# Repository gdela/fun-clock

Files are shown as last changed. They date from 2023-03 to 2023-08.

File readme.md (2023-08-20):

Alarm Clock with Oversleep Prevention
=====================================

Features:

- automatic time synchronization with NTP server over WiFi
- old-style TIL311 hexadecimal display
- two alarm settings: for weekdays and for weekends
- alarm starts gently with some nature sounds for a couple of minutes
- alarm ends with very loud energetic music to make sure you hear it
- to turn alarm off you need to read three random numbers and enter them back
- this makes sure that you are fully awake and do not oversleep the alarm

There is no documentation for this project, as this is rather for my own purposes.
Feel free to reverse-engineer it.

<p align="center">
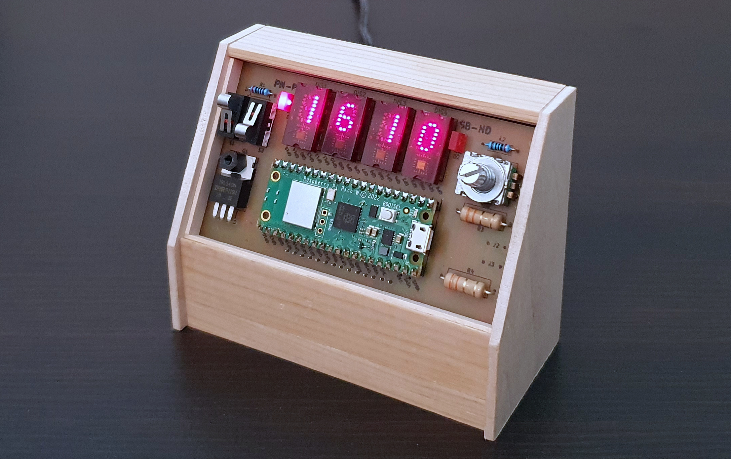
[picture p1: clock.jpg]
    
</p>

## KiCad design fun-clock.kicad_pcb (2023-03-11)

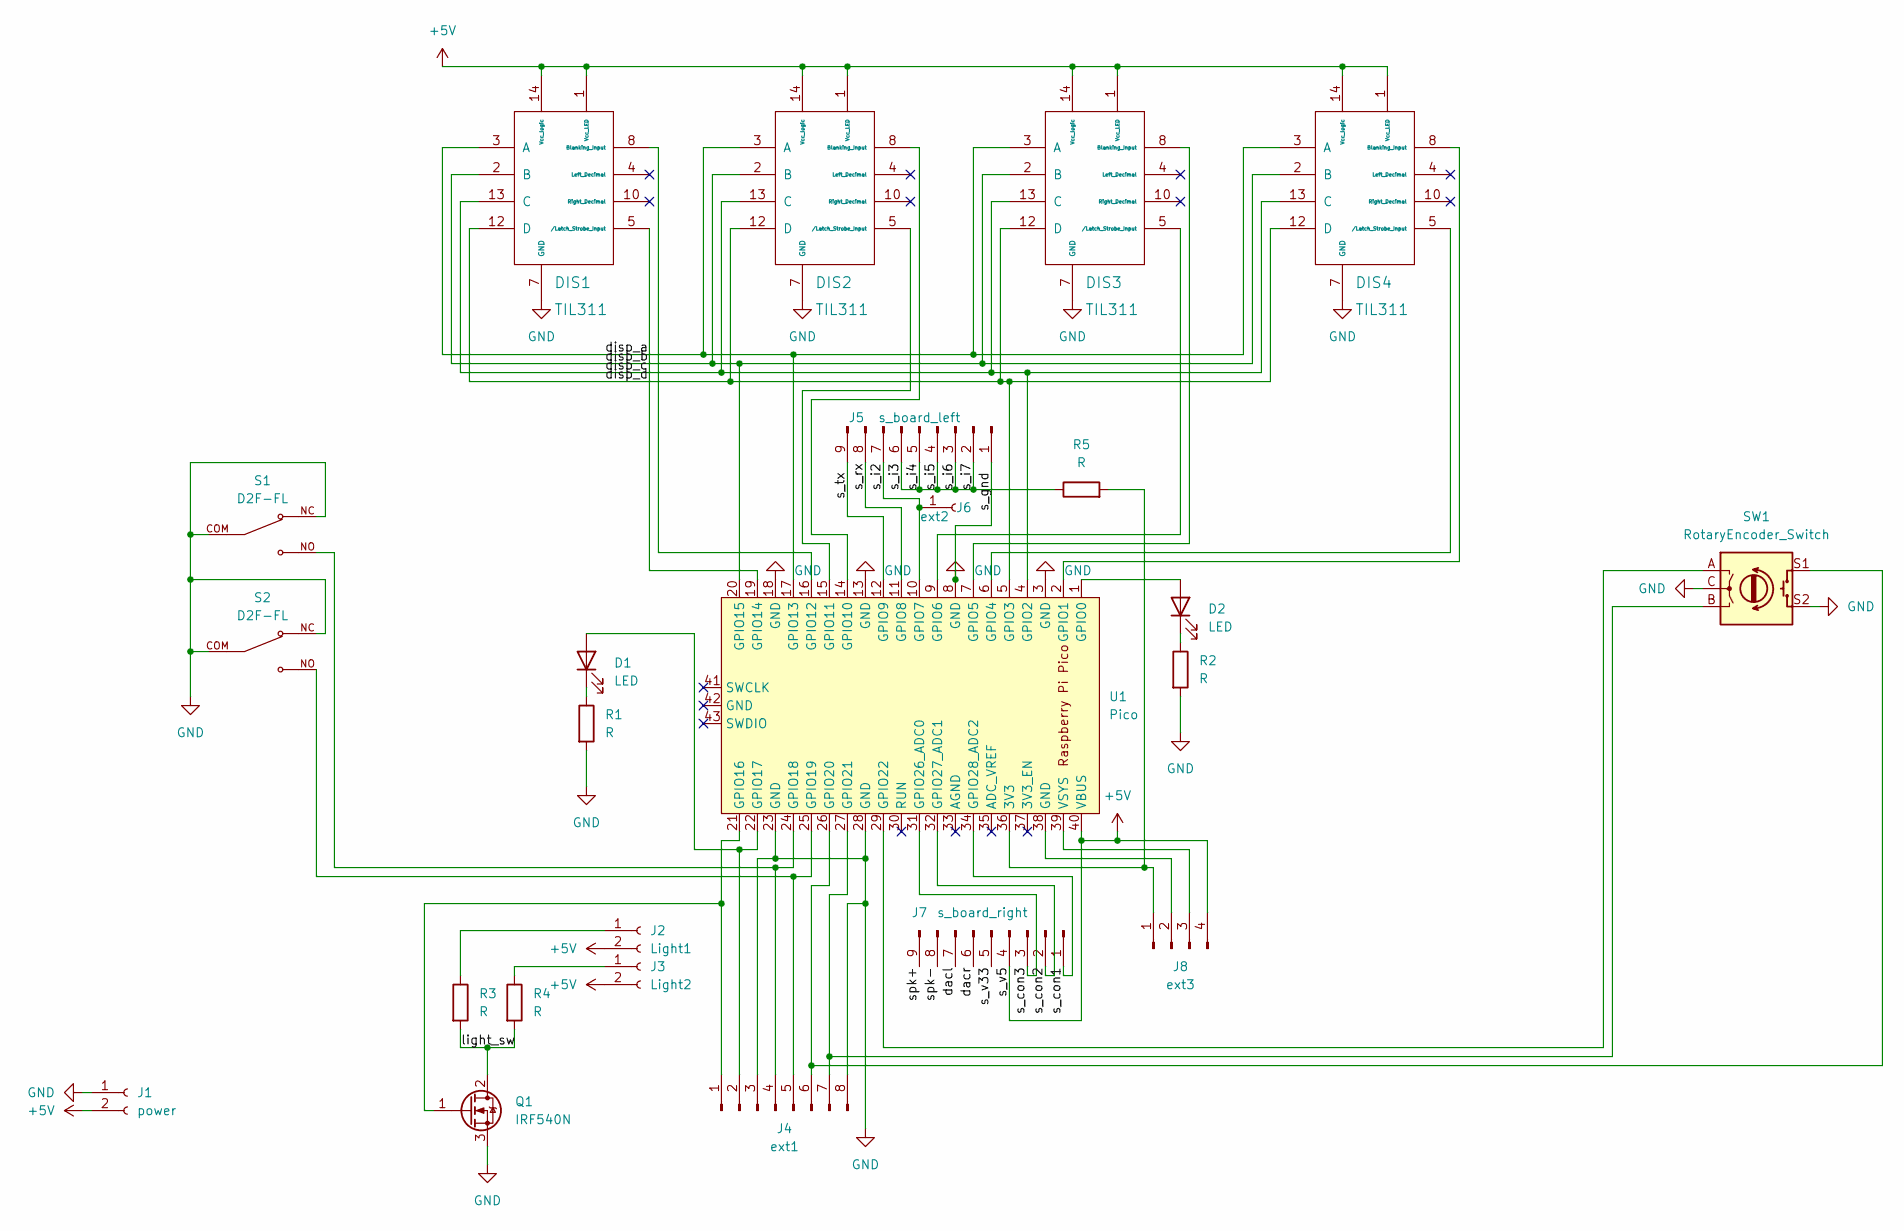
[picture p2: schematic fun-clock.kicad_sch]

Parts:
D1, D2: LED; LED_Rectangular_W5.0mm_H2.0mm
DIS1, DIS2, DIS3, DIS4: TIL311
J1: power; TerminalBlock_bornier-2_P5.08mm
J2: Light1; SolderWire-0.5sqmm_1x02_P4.8mm_D0.9mm_OD2.3mm
J3: Light2; SolderWire-0.5sqmm_1x02_P4.8mm_D0.9mm_OD2.3mm
J4: ext1; PinHeader_1x08_P2.54mm_Vertical
J5: s_board_left; PinHeader_1x09_P2.54mm_Vertical
J6: ext2; TestPoint_Pad_2.0x2.0mm
J7: s_board_right; PinHeader_1x09_P2.54mm_Vertical
J8: ext3; PinHeader_1x04_P2.54mm_Vertical
Q1: IRF540N; TO-220-3_Horizontal_TabDown
R1, R2, R5: R; R_Axial_DIN0207_L6.3mm_D2.5mm_P10.16mm_Horizontal
R3, R4: R; R_Axial_DIN0414_L11.9mm_D4.5mm_P15.24mm_Horizontal
S1, S2: D2F-FL; SW_D2F-FL; PARTREV N/A
SW1: RotaryEncoder_Switch; mojenkoder
U1: Pico; RPi_Pico_SMD_TH

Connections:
+5V: DIS1.1 (Vcc_LED), DIS1.14 (Vcc_logic), DIS2.1 (Vcc_LED), DIS2.14 (Vcc_logic), DIS3.1 (Vcc_LED), DIS3.14 (Vcc_logic), DIS4.1 (Vcc_LED), DIS4.14 (Vcc_logic), J1.2, J2.2, J3.2, J7.4, J8.4, U1.40 (VBUS)
/dacl: J7.7
/dacr: J7.6
/disp_a: DIS1.3 (A), DIS2.3 (A), DIS3.3 (A), DIS4.3 (A), U1.17 (GPIO13)
/disp_b: DIS1.2 (B), DIS2.2 (B), DIS3.2 (B), DIS4.2 (B), U1.20 (GPIO15)
/disp_c: DIS1.13 (C), DIS2.13 (C), DIS3.13 (C), DIS4.13 (C), U1.4 (GPIO2)
/disp_d: DIS1.12 (D), DIS2.12 (D), DIS3.12 (D), DIS4.12 (D), U1.5 (GPIO3)
/light_sw: Q1.2 (D), R3.2, R4.2
/s_con1: J7.1, U1.34 (GPIO28_ADC2)
/s_con2: J7.2, U1.32 (GPIO27_ADC1)
/s_con3: J7.3, U1.31 (GPIO26_ADC0)
/s_i2: J5.7, J6.1, U1.10 (GPIO7)
/s_i3: J5.2, J5.3, J5.4, J5.5, J5.6, R5.1
/s_rx: J5.8, U1.11 (GPIO8)
/s_tx: J5.9, U1.12 (GPIO9)
/s_v33: J7.5
/spk+: J7.9
/spk-: J7.8
GND: DIS1.7 (GND), DIS2.7 (GND), DIS3.7 (GND), DIS4.7 (GND), J1.1, J4.3, J4.8, J5.1, Q1.3 (S), R1.2, R2.2, S1.COM, S1.NC, S2.COM, S2.NC, SW1.C, SW1.S2, U1.3 (GND), U1.8 (GND), U1.13 (GND), U1.18 (GND), U1.23 (GND), U1.28 (GND)
unnamed: D1.1 (K), R1.1
unnamed: D1.2 (A), J4.2, U1.22 (GPIO17)
unnamed: D2.1 (K), R2.1
unnamed: D2.2 (A), U1.1 (GPIO0)
unnamed: DIS1.5 (/Latch_Strobe_Input), U1.19 (GPIO14)
unnamed: DIS1.8 (Blanking_Input), U1.16 (GPIO12)
unnamed: DIS2.5 (/Latch_Strobe_Input), U1.15 (GPIO11)
unnamed: DIS2.8 (Blanking_Input), U1.14 (GPIO10)
unnamed: DIS3.5 (/Latch_Strobe_Input), U1.9 (GPIO6)
unnamed: DIS3.8 (Blanking_Input), U1.7 (GPIO5)
unnamed: DIS4.5 (/Latch_Strobe_Input), U1.6 (GPIO4)
unnamed: DIS4.8 (Blanking_Input), U1.2 (GPIO1)
unnamed: J2.1, R3.1
unnamed: J3.1, R4.1
unnamed: J4.1, Q1.1 (G), U1.21 (GPIO16)
unnamed: J4.4, S1.NO, U1.24 (GPIO18)
unnamed: J4.5, S2.NO, U1.25 (GPIO19)
unnamed: J4.6, SW1.S1, U1.26 (GPIO20)
unnamed: J4.7, SW1.B, U1.27 (GPIO21)
unnamed: J8.1, R5.2, U1.36 (3V3)
unnamed: J8.2, U1.38 (GND)
unnamed: J8.3, U1.39 (VSYS)
unnamed: SW1.A, U1.29 (GPIO22)

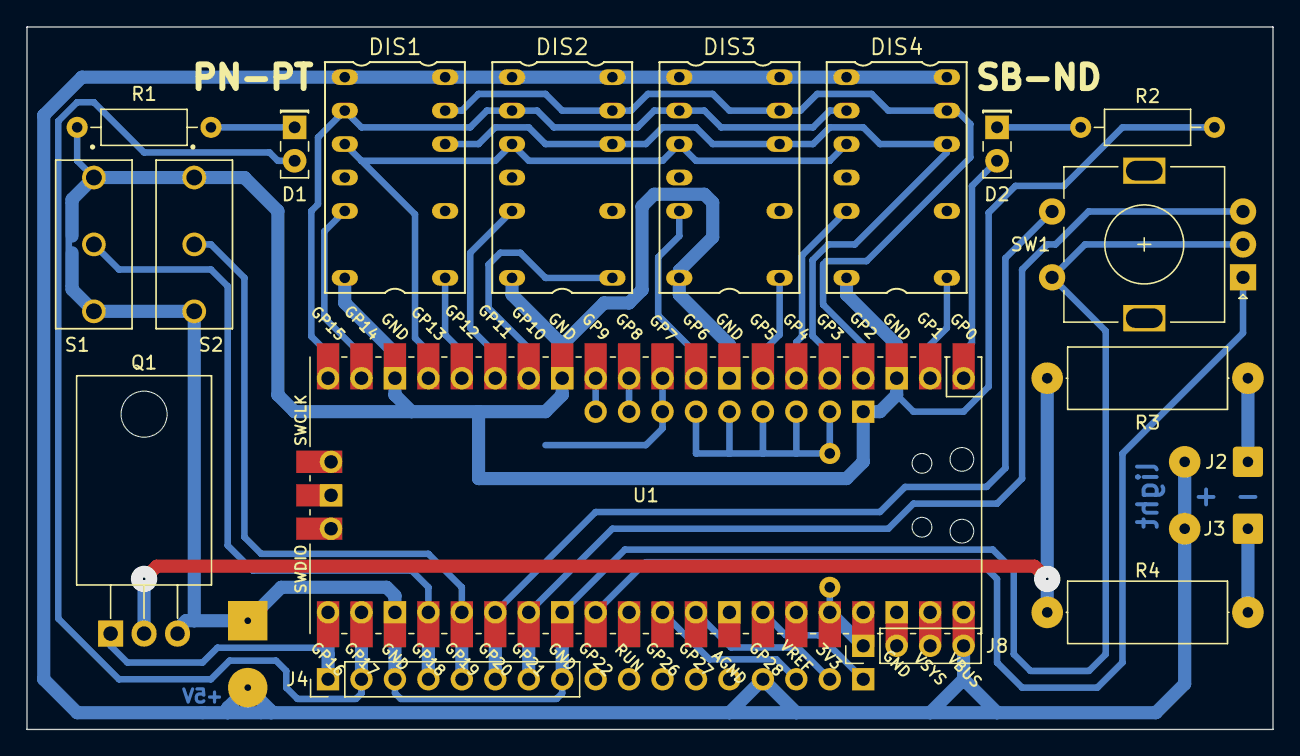
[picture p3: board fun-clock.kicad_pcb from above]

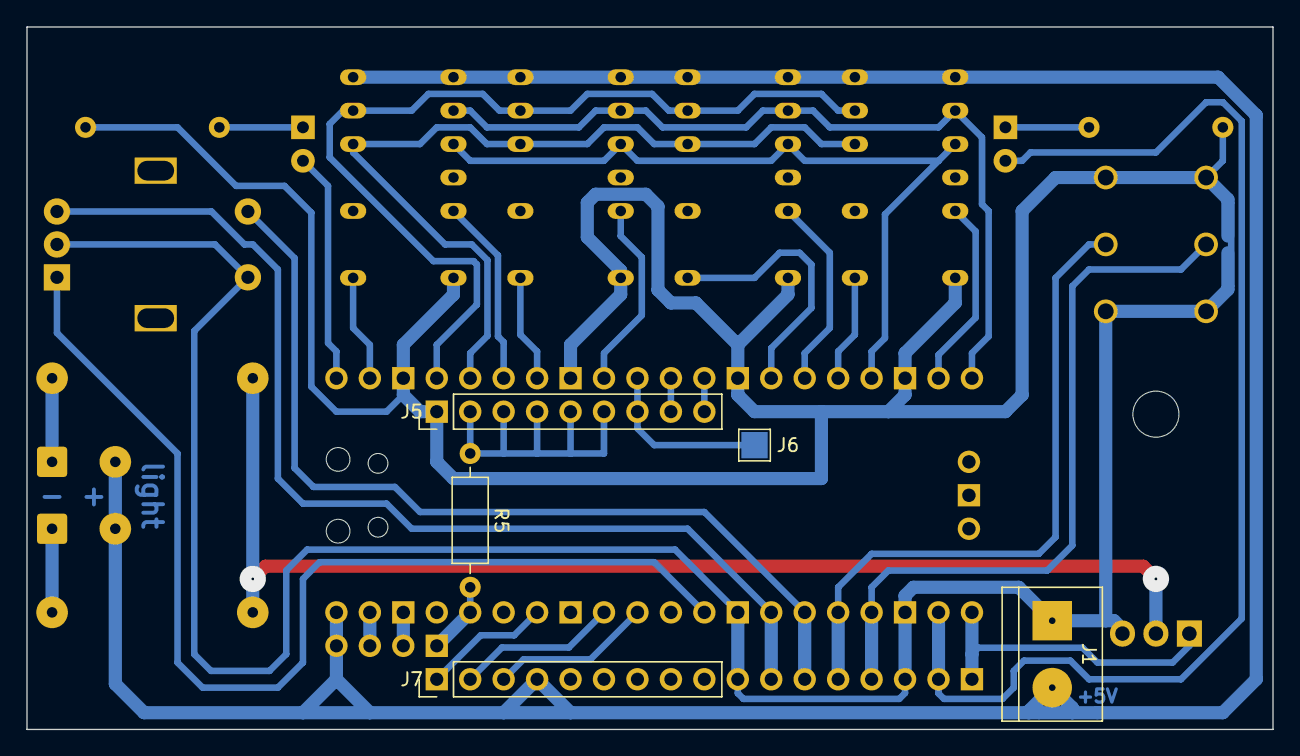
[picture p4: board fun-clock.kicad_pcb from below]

Board: 2 copper layers, 94.6 x 53.3 mm, 24 parts (5 on the bottom side), 37 nets.

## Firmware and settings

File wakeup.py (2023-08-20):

from time import sleep
from random import randint
from timeutils import JustTime
from display import set_digit, display_dec, display_blank
from picker import pick_hex_digits, pick_dec_digits
from sound import start_sound, stop_sound, set_current_sound, get_current_sound, play_single_sound
from peripherals import lights_on, lights_off


MODE_NORMAL = const(0)
MODE_WAKING_UP = const(1)
MODE_WOKE_UP = const(2)

current_mode = MODE_NORMAL


def update_wakeup(alarm: JustTime, clock: JustTime):
    global current_mode
    diff = alarm.diff_seconds_to(clock) / 60

    if diff <= 0:
        _handle_normal_period()
        
    elif diff <= 1:
        _handle_wakeup_period('alarm')
        
    elif diff <= 5:
        _handle_wakeup_period('strong')
        
    elif diff <= 9:
        _handle_wakeup_period('gentle')
        
    else:
        _handle_normal_period()
        

def wakeup_in_progress():
    global current_mode
    return current_mode == MODE_WAKING_UP


def _handle_wakeup_period(sound):
    global current_mode
    set_current_sound(sound)
    if current_mode == MODE_NORMAL:
        current_mode = MODE_WAKING_UP
        start_sound()
        lights_on()
        

def _wakeup_confirmed():
    global current_mode
    current_mode = MODE_WOKE_UP


def _handle_normal_period():
    global current_mode
    if current_mode != MODE_NORMAL:
        current_mode = MODE_NORMAL
        stop_sound()
        lights_off()


def confirm_wakeup():
    print('confirming wakeup')
    enter_password()
    stop_sound()
    
    try:
        successes = 0
        failures = 0
        while successes < 3 and failures < 5:
            result = memory_game()
            if result:
                successes += 1
            else:
                failures += 1
            print(f'successes {successes}, failures {failures}')
        
        if successes == 3:
            print('wakeup confirmed')
            _wakeup_confirmed()
        else:
            start_sound()
        
    except GameNotPlayed as e:
        start_sound()
    


def enter_password():
    guess = None
    for word in [0xCAFE, 0xBABE]:
        while guess != word:
            guess = pick_hex_digits(0xAAAA, 0xFFFF, stop_hex=word)
        sleep(1)
    display_blank()


def memory_game():
    display_blank()
    secret = randint(1, 9999)
    secret_str = f'{secret:04d}'
    digits = random_digits_order()
    for digit in digits:
        set_digit(digit, int(secret_str[digit]))
        sleep(0.5)
        set_digit(digit, None)
    guess = pick_dec_digits(0, 9999, stop_dec=secret, timeout_seconds=15)
    display_dec(guess)
    play_single_sound('good' if guess == secret else 'bad')
    sleep(1)
    display_blank()
    print(f'guessed {guess} while secret was {secret}')
    if guess == 0:
        raise GameNotPlayed()
    return guess == secret


def random_digits_order():
    result_list = []
    while len(result_list) < 4:
        next_digit = randint(0,3)
        if not next_digit in result_list:
            result_list.append(next_digit)
    return result_list


class GameNotPlayed(Exception):
    pass


if __name__ == '__main__':
    def simulate_confirm_wakeup():
        stop_sound()
        _wakeup_confirmed()
    
    #enter_password()
    #result = memory_game()
    #print(f'memory game success: {result}')
    #confirm_wakeup()
    
    update_wakeup(JustTime(8,30), JustTime(8,00))
    print(f'at -30 min, mode: {current_mode}, sound: {get_current_sound()}')

    update_wakeup(JustTime(8,30), JustTime(8,20))
    print(f'at -10 min, mode: {current_mode}, sound: {get_current_sound()}')

    update_wakeup(JustTime(8, 30), JustTime(8, 22))
    print(f'at  -8 min, mode: {current_mode}, sound: {get_current_sound()}')

    update_wakeup(JustTime(8,30), JustTime(8,25))
    print(f'at  -5 min, mode: {current_mode}, sound: {get_current_sound()}')

    update_wakeup(JustTime(8,30), JustTime(8,29))
    print(f'at  -1 min, mode: {current_mode}, sound: {get_current_sound()}')
    
    simulate_confirm_wakeup()
    
    update_wakeup(JustTime(8,30), JustTime(8,30))
    print(f'at   0 min, mode: {current_mode}, sound: {get_current_sound()}')

    update_wakeup(JustTime(8,30), JustTime(8,31))
    print(f'at  +1 min, mode: {current_mode}, sound: {get_current_sound()}')
    
    

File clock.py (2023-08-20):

import os, rtc
from micropython import const
from time import struct_time
from network import get_socket_pool
from adafruit_ntp import NTP
from display import display_dec
from peripherals import drive_led

rtc = rtc.RTC()

WEEKDAY = const(0)
WEEKEND = const(1)
day_type = WEEKDAY
time_zone_offset = 1
last_synchronization_day = -1


def current_day_type():
    return day_type


def update_clock(now:struct_time = None):
    if now == None:
        now = rtc.datetime
    determine_day_type(now)
    global last_synchronization_day
    if last_synchronization_day != now.tm_mday:
        synchronize_clock()
        last_synchronization_day = now.tm_mday
    display_dec(now.tm_hour * 100 + now.tm_min)


def determine_day_type(now:struct_time):
    global day_type
    if now.tm_wday < 4 or (now.tm_wday == 4 and now.tm_hour <= 15):  # up to friday 15:59
        day_type = WEEKDAY
    elif now.tm_wday == 6 and now.tm_hour > 15:  # since sunday 16:00
        day_type = WEEKDAY
    else:
        day_type = WEEKEND
    drive_led(day_type, 0.2)


def load_time_zone_offset():
    global time_zone_offset
    with open('offset.txt', 'r') as file:
        contents = file.read()
        time_zone_offset = int(contents)
    print(f'loaded time zone offset: {time_zone_offset}')


def store_time_zone_offset():
    with open('offset.txt', 'w') as file:
        file.write(str(time_zone_offset))


try:
    load_time_zone_offset()
except Exception as e:
    print('cannot load time zone offset: ' + str(e))


def switch_dst():
    global time_zone_offset
    time_zone_offset = 2 if time_zone_offset == 1 else 1
    store_time_zone_offset()
    print(f'changed time zone offset to: {time_zone_offset}')
    synchronize_clock()


def synchronize_clock():
    try:
        ntp = NTP(get_socket_pool(), tz_offset=time_zone_offset, socket_timeout=10)
        now = rtc.datetime = ntp.datetime
        print(f'synchronized to: {now.tm_year}-{now.tm_mon:02d}-{now.tm_mday:02d} {now.tm_hour:02d}:{now.tm_min:02d}')
    except Exception as e:
        print('cannot synchronize: ' + str(e))


def now_with(**modifications) -> struct_time:
    source = rtc.datetime
    target = {}
    for a in [a for a in dir(source) if a.startswith('tm_')]:
        target[a] = getattr(source, a)
        if a in modifications:
            target[a] = modifications[a]
    return struct_time([
        target['tm_year'],
        target['tm_mon'],
        target['tm_mday'],
        target['tm_hour'],
        target['tm_min'],
        target['tm_sec'],
        target['tm_wday'],
        target['tm_yday'],
        target['tm_isdst']
    ])

        
if __name__ == '__main__':
    #switch_dst()
    #synchronize_clock()
    update_clock()  # will trigger auto synchronization
    update_clock()  # will skip auto synchronization in the same day
    update_clock(now_with(tm_mday=0))  # will synchronize again in new day
    print(f'current rtc datetime = {rtc.datetime}')
    
    determine_day_type(rtc.datetime)
    print(f'day type currently: {day_type}')
    determine_day_type(now_with(tm_wday=0, tm_hour=00))  # monday midnight
    print(f'day type currently: {day_type} [0 expected]')
    determine_day_type(now_with(tm_wday=4, tm_hour=12))  # friday noon
    print(f'day type currently: {day_type} [0 expected]')
    determine_day_type(now_with(tm_wday=4, tm_hour=22))  # friday evening
    print(f'day type currently: {day_type} [1 expected]')
    determine_day_type(now_with(tm_wday=2, tm_hour=12))  # wednesday noon
    print(f'day type currently: {day_type} [0 expected]')
    determine_day_type(now_with(tm_wday=5, tm_hour=12))  # saturday noon
    print(f'day type currently: {day_type} [1 expected]')
    determine_day_type(now_with(tm_wday=6, tm_hour=22))  # sunday evening
    print(f'day type currently: {day_type} [0 expected]')
    determine_day_type(now_with(tm_wday=6, tm_hour=12))  # sunday noon
    print(f'day type currently: {day_type} [1 expected]')
    
    
